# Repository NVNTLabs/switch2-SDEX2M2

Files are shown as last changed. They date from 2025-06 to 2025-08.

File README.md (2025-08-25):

# NVNT's SDEX2M2 (MicroSD Express to M.2) Adapter Project



SDEX2M2 (Micro**SD** **Ex**press to **M2**) is an adapter for the Nintendo Switch 2 which converts the MicroSD Express slot to a NVME M.2 (M-Key) slot. Think MicroSD Express cards are difficult to find or expensive? Looking to expand your storage for cheaper? Just use the NVME M.2 SSD that you have, and/or can easily find! The project is open source hardware under the GPLv3 License.

This project also encompasses the sister-project of "MicroSD Express to SD Express" adapter, which is a pin-to-pin conversion kit allowing full size SD Express cards to be used on the Nintendo Switch 2.

---

## 📚 Table of Contents
- **Introduction**
  - [Goals](#goals)
  - [Status](#status)
  - [Warnings](#warnings)
- **Assets & Hardware Info**
  - [Bill of Materials (BOM)](#bill-of-materials-bom)
  - [PINOUT & LEGEND](#pinout--legend)
    - [MicroSD Express to M.2 NVMe Mapping](#microsd-express-to-m2-nvme-mapping)
    - [M.2 NVMe Pinout](#m2-nvme-pinout)
    - [MicroSD Express Pinout](#microsd-express-pinout)
- **PCB's / Boards**
  - [Wiring Schematic](#wiring-schematic)
  - [MicroSD Express Dummy Card](#microsd-express-dummy-card)
  - [MicroSD Express to FPC Flex Cable Connector](#microsd-express-to-fpc-flex-cable-connector)
  - [MicroSD Express Breakout Board](#microsd-express-breakout-board)
  - [NVMe M.2 SSD Breakout Board](#nvme-m2-ssd-breakout-board)
  - [MicroSD Express to SD Express Prototype Adapter](#microsd-express-to-sd-express-prototype-adapter)
  - [SDEX2SDEX MicroSD Express to NVMe M.2 Prototype Pin-to-Pin Adapter WIP](#sdex2sdex-microsd-express-to-nvme-m2-prototype-pin-to-pin-adapter)
  - [MicroSD Express Sniffer for Switch 2 Handshake](#microsd-express-sniffer)
- [License](#license)

---

## How is this possible?

This is possible because the Nintendo Switch 2's MicroSD Express slot supports the SD Express 7.1 standard, which exposes a **true PCIe Gen3 x1 interface** and utilizes the **NVMe protocol** for communication.

This adapter simply maps PCIe x1 from the Switch 2’s MicroSD Express slot to a standard M.2 2230 NVMe SSD. After further research and review from users, an onboard mcu/fpga will be required for the handshake process with the Switch 2.

Currently, we've developed a sniffer board which will be used to facilitate this.

---

## Goals

- ✅ Create Pinout & Pin Definitions (UPDATED!)
- ✅ Create Footprints for MicroSD Express
- ✅ Create Schematic for PCB layout
- ✅ Create Dummy MicroSD Express Card V2
- ✅ Create M.2 Breakout for prototyping (Updated 2-layer PCB)
- ✅ Create MicroSD Express Breakout Board V0.1 (Updated 2-layer PCB)
- ✅ Create MicroSD Express to SD Express Adapter (Experimental, Updated 2-layer PCB)
- ✅ Create BOM for fabrication and sourcing (WIP)
- ✅ Create MicroSD Express to NVMe M.2 SSD Pin to Pin Adapter (Proof of concept)
- ✅ Create basic 3D printable enclosures/shells for the PCBs
- ✅ Create MicroSD Express Sniffer PCB for capturing Nintendo Switch 2 Handshake (for getting NVMe drives to be functional!)
- 🔲 Create MicroSD Express to NVMe M.2 SSD Adapter with FPGA/MCU Proto (for handshake with Nintendo Switch 2) **(in progress)**
- ✅ Create MicroSD Express to Flex Cable Adapter
- 🔲 Create Flex Cable to NVMe Adapter **(in progress)**
- 🔲 Create MicroSD Express to NVMe M.2 SSD Dock **(in progress)**

---

## Status

Work in progress. Currently, a prototype with handshake capability with the Switch 2 and also designs for the final product design are being worked on.

An early proof of concept prototype of the SDEX2M2 MicroSD Express to NVMe M.2 SSD Adapter has been made, but it does lack Switch 2 compatibility. 

**For prototyping, a new MicroSD Express sniffer has been uploaded which is used for capturing the signal/handshake that the Nintendo Switch 2 uses for communicating with the MicroSD Express card. With this, we are one step closer to our goal!**

Additionally, production-ready 2-layer PCBs for the MicroSD Express breakout board, NVMe breakout board, and the MicroSD Express to FPC Connector (which may be used in the final design) have been uploaded.

The MicroSD Express to SD Express adapter production ready prototype board has been uploaded as well, for users with full-size SD Express cards.

Basic 3D printable shells have been added too, for convenience.

---

## Warnings

- Use at your own risk. We are **not liable** for any damage to your drive, Switch 2, or other devices.
- Only use **low-voltage, low-power M.2 2230 NVMe drives**.
- **Do not use this in legacy MicroSD slots** (e.g., original Nintendo Switch).
  
---

## Bill of Materials (BOM)

| Reference | Quantity | Description | Part Number | Manufacturer |
|---|---|---|---|---|
| J2 | 1 | M.2 Socket (M-Key, 2230) | 114020 | Amphenol |
| FB1 | 1 | Ferrite Bead 220Ω@100MHz 0603 | BLM18PG221SN1D | Murata/OEM |
| PCB | 1 | 4-Layer PCB | N/A | Fabricated | * |
|* | 1 | 10kΩ – 100kΩ Pull Up Resistor (Optional) | N/A | * |

The optional resistor is for the PERST# lane, may help with state when idle. Not sure if needed until prototyping commences.

---

## PINOUT & LEGEND

### MicroSD Express to M.2 NVMe Mapping

| microSD Express Pin  | PCIe Function | M.2 M-Key Pin(s) | M.2 Function |
| --- | --- | --- | --- |
| 7 (Row 1) | REFCLK+ | B10 | REFCLK+ |
| 8 (Row 1) | REFCLK− | B11 | REFCLK− |
| 2 (Row 1) | PERST# | A11 | PERST# |
| 1 (Row 1) | CLKREQ# | B8 | CLKREQ# |
| 11 (Row 2) | TX+ | B23 | PCIe TX+ |
| 12 (Row 2) | TX− | B24 | PCIe TX− |
| 14 (Row 2) | RX- | A21 | PCIe RX+ |
| 15 (Row 2) | RX+ | A22 | PCIe RX− |
| 4 (Row 1) | 3.3V VDD | B2, B3, B4 | 3.3V Power |
| 6, 10, 13, 16 | GND | A1, A4, etc. | Ground |

---

### M.2 NVMe Pinout

| Pin | Name | Function |
|---|---|---|
| A11 | PERST# | PCIe Reset |
| A21 | RX+ | PCIe RX+ (to host) |
| A22 | RX− | PCIe RX− (to host) |
| B10 | REFCLK+  | PCIe Reference Clock + |
| B11 | REFCLK−  | PCIe Reference Clock − |
| B23 | TX+ | PCIe TX+ (from host) |
| B24 | TX− | PCIe TX− (from host) |
| B2–B4 | 3.3V | Power Supply |
| A1, A4  | GND | Ground Pins |

---

### MicroSD Express Pinout

In SD Mode &* PCIe Mode

| Pin | Row 1 Contact | SD Mode Function | PCIe Mode Function |
| --- | --- | --- | --- |
| 1 | DAT2 | Data Line 2 | CLKREQ# (Power / Signal Mgmt) |
| 2 | DAT3 / CD | Data Line 3 / CD | PERST# (Reset) |
| 3 | CMD | Command Line | CMD (unused in PCIe mode) |
| 4 | VDD | 3.3V Power | 3.3V Power |
| 5 | CLK | Clock Line | CLK (unused in PCIe mode) |
| 6 | VSS | Ground | Ground |
| 7 | DAT0 | Data Line 0 | REFCLK+ (PCIe Ref Clock) |
| 8 | DAT1 | Data Line 1 | REFCLK− (PCIe Ref Clock) |

| Pin | Row 2 Contact | PCIe Function |
| --- | --- | --- |
| 9 | 1V8 | 1.8 Volts |
| 10  | VSS2 | Ground for isolation |
| 11  | TX+ | PCIe TX+ (Transmit) |
| 12  | TX- | PCIe TX- (Transmit) |
| 13  | VSS3 | Ground for isolation |
| 14  | RX- | PCIe RX- (Receive) |
| 15  | RX+ | PCIe RX+ (Receive) |
| 16  | VSS4 | Ground for isolation |
| 17  | 1V2 | 1.2 Volts |

Please note: Row 2 is only operational in PCIe Mode. Row 2 is based on M1cha's (https://github.com/M1cha/sdexpress_pcbs) schematic.

---

### MicroSD Express Card to SD Express Slot Pinout

| **MicroSD Express Pin** | **Function (PCIe Mode)**  | **SD Express Slot Pin** | **Function in Slot** | 
| --- | --- | --- | --- |
| 1 DAT2 | CLKREQ# | 51 | CLKREQ# (Power / Signal Mgmt) | 
| 2 DAT3 / CD | PERST# | 52 | PERST# (Reset line)  |
| 3 CMD | CMD (unused) | — | CMD (unused in PCIe mode) | 
| 4 VDD | 3.3V VDD | 18, 48 | VDD |
| 5 CLK | CLK (unused) | — | — | 
| 6 VSS | GND (VSS1) | 17, 47, 49, 50 | GND |
| 7 DAT0 | REFCLK+ | 45 | REFCLK+ | 
| 8 DAT1 | REFCLK− | 46 | REFCLK− | 
| 9 1V8 | 1.8V VDD (VDD2) | 1, 2, 3 (often shared)  | VDD 1.8 Volts | 
| 10 VSS2 | GND (VSS2) | 17, 47, etc. | GND (GND Ground for isolation)| 
| 11 TX+ | TX+ | 39 | PCIe TX+ (Transmit)  |
| 12 TX- | TX− | 41 | PCIe TX- (Transmit)  |
| 13 VSS3 | GND  (VSS3) | 17, 47, etc. | GND (Ground for isolation)| 
| 14 RX- | RX− | 35 | PCIe RX- (Receive)|
| 15 RX+ | RX+ | 37 | PCIe RX+ (Receive)|
| 16 VSS4 | GND (VSS4) | 17, 47, etc. | GND (Ground for isolation)| 
| 17 1V2 | 1.2V VDD (VDD3, optional) | — | Not used (May be unused)|

Note: WIP

---

### Wiring Schematic



Still a WIP. Some discrepencies may exist.

---

### MicroSD Express Dummy Card

A dummy card has been created (thanks to M1cha's design examples!), for reference. Files have been attached.



---

### MicroSD Express to FPC Flex Cable Connector

A MicroSD Express to Flex Cable Connector (FPC) has been created for reference. Schematic, Geberer and PCB files have been attached.



---

### MicroSD Express Breakout Board

A production-ready 2-layer breakout board for MicroSD Express has been created (codenamed: "The Key"). Files have been attached in the repo. The purpose of this is for prototyping with a breadboard.



---

### NVMe M2 SSD Breakout Board

A breakout board for a NVMe M.2 SSD slot (M-key) has been created. Files have been attached in the repo. The purpose of this is for prototyping with a breadboard.



---

### MicroSD Express to SD Express Prototype Adapter

An extremely experimental production ready MicroSD Express to **Full Size** SD Express Slot adapter has been made. The purpose of this is to allow full size SD Express cards to be inserted into the Nintendo Switch 2.

Please be aware that it is untested as of the time of writing.



---

### SDEX2SDEX MicroSD Express to NVMe M.2 Prototype Pin-to-Pin Adapter

A production-ready (but experimental) 2-layer PCB for the SDEX2M2 MicroSD Express to NVMe M.2 adapter has been uploaded. 

Please note that this is a pin-to-pin adapter, and is not capable of completing the handshake with Nintendo Switch 2. It is for proof of concept, and is untested as of the time of writing.



---

### MicroSD Express Sniffer

A experimental PCB MicroSD Express sniffer has been uploaded. **This is used for capturing the handshake signal/commands from the Nintendo Switch 2**.

Please note: The MicroSD Express card slot on the PCB in the picture below is for placeholder only as it doesn't exactly match the dimensions of the one used in the actual PCB itself.



---

## License

NVNT SDEX2M2 License

This hardware design is licensed under the **CERN Open Hardware License Version 2 – Strongly Reciprocal (CERN-OHL-S v2)**.

The software/firmware design is licensed under the **GNU General Public License v3.0 (GPLv3)**

The documentation and readme is licensed under the **Creative Commons Attribution-ShareAlike 4.0 International (CC-BY-SA 4.0)**.

See [LICENSE](LICENSE.txt), [LICENSE-HARDWARE](LICENSE-HARDWARE.txt) and [LICENSE-DOCUMENTATION](LICENSE-DOCUMENTATION.txt) for more information.

---

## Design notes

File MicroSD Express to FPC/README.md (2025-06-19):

# microSD Express card to FPC

> [!WARNING]
> This is WIP and based on M1cha's perimeters.

JLCPCB order parameters:

- **Gerber file**: usdex_card-to-fpc_Y5
- **Build Time**: 5-6 days
- **Base Material**: FR-4
- **Layers**: 6
- **Dimension**: 11 mm* 18 mm
- **PCB Qty**: 5
- **Product Type**: Industrial/Consumer electronics
- **Different Design**: 1
- **Delivery Format**: Single PCB
- **PCB Thickness**: 0.8mm
- **Specify Stackup**: yes JLC06081H-2116
- **Impedance Control**: No requirement
- **PCB Color**: Green
- **Silkscreen**: White
- **Material Type**: FR-4 TG155
- **Via Covering**: Epoxy Filled & Capped
- **Surface Finish**: ENIG Gold Fingers: 2U"
- **Deburring/Edge rounding**: Yes
- **Outer Copper Weight**: 1 oz
- **Inner Copper Weight**: 0.5 oz
- **Gold Fingers**: Yes
- **Beveling**: No
- **Electrical Test**: Flying Probe Fully Test
- **Castellated Holes**: no
- **Press-Fit Hole**: No
- **Edge Plating**: No
- **Mark on PCB**: Remove Mark
- **Blind Slot**: No
- **Min via hole size/diameter**: 0.3mm/(0.4/0.45mm)
- **4-Wire Kelvin Test**: No
- **Paper between PCBs**: No
- **Appearance Quality**: IPC Class 2 Standard
- **Confirm Production file**: Yes
- **Silkscreen Technology**: Ink-jet/Screen Printing Silkscreen
- **Package Box**: With JLCPCB logo
- **Inspection Report**: No
- **Board Outline Tolerance**: ±0.2mm(Regular)

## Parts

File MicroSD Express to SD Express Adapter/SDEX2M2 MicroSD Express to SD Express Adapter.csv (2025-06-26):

Reference | Qty | Value | DNP | Exclude from BOM | Exclude from Board | Footprint | Datasheet
J1 | 1 | SDEX2M2 MicroSD Express to SD Express Adapter |  |  |  | m1cha:usdex-male-open_bottom
J2 | 1 | GSD2100407THR |  |  |  | GSD2100407THR:AMPHENOL_GSD2100407THR

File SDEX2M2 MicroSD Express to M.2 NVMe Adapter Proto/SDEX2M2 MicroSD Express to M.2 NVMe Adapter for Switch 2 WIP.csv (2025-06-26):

Reference | Qty | Value | DNP | Exclude from BOM | Exclude from Board | Footprint | Datasheet
J1 | 1 | SDEX2M2 MicroSD Express to SD Express Adapter |  |  |  | m1cha:usdex-male-open_bottom
J2 | 1 | Conn_01x02_Pin |  |  |  | Connector_PinHeader_2.00mm:PinHeader_1x02_P2.00mm_Vertical | ~
J4 | 1 | 10130616-067R2LF |  |  |  | 10130616-067R2LF:AMPHENOL_10130616-067R2LF
R1 | 1 | R_Small (Pull-Up) 33kΩ |  |  |  | Resistor_SMD:R_0603_1608Metric | ~

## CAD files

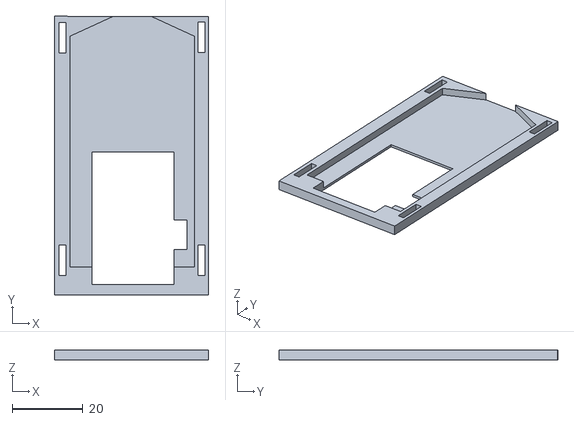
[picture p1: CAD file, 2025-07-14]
3D Printable Shells/SDEX2M2 Prototype Shell Top.stl
43.5 x 78.6 x 2.96

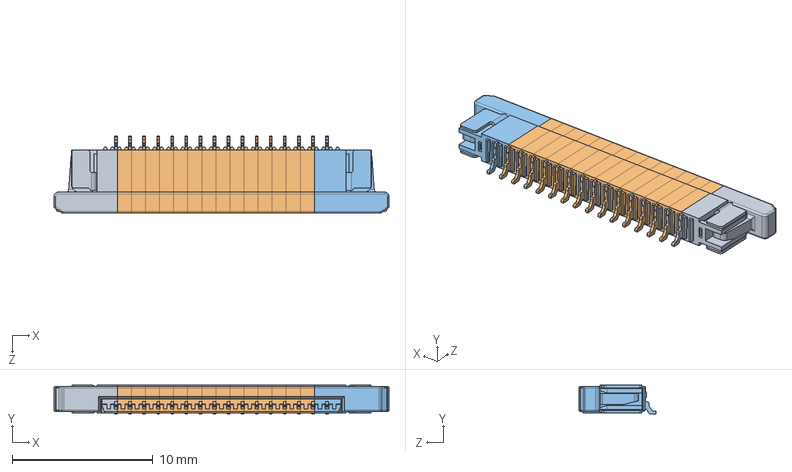
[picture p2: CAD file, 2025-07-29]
MicroSD Express to FPC/F52R-1A7H1-11016--3DModel-STEP-56544.STEP
23.8 x 2.05 x 5.50 mm
F52R_L.STEP
F52R_M.STEP x 14
F52R_R.STEP

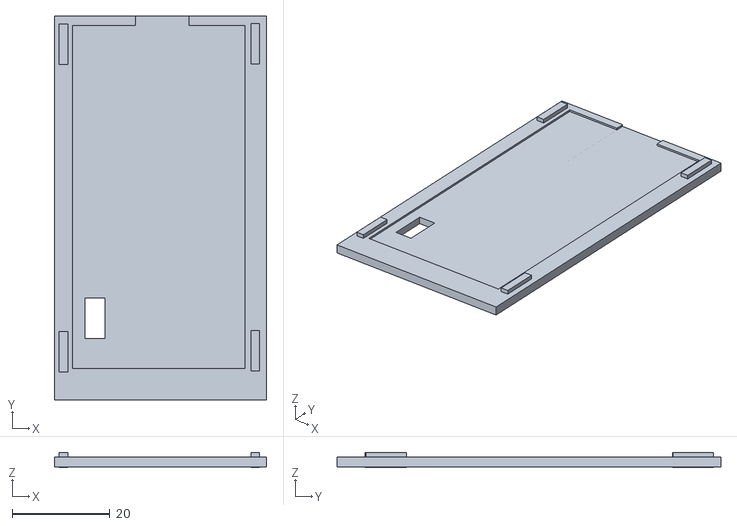
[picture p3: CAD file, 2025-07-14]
3D Printable Shells/SDEX2M2 Prototype Shell Bottom.stl
43.5 x 78.7 x 3.00

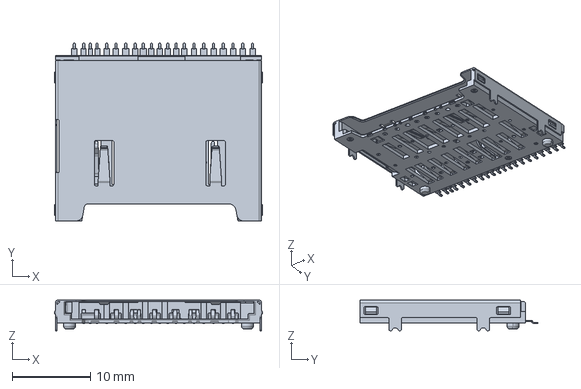
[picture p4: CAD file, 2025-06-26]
MicroSD Express to SD Express Adapter/GSD2100407THR--3DModel-STEP-418109.STEP
26.6 x 22.8 x 3.95 mm

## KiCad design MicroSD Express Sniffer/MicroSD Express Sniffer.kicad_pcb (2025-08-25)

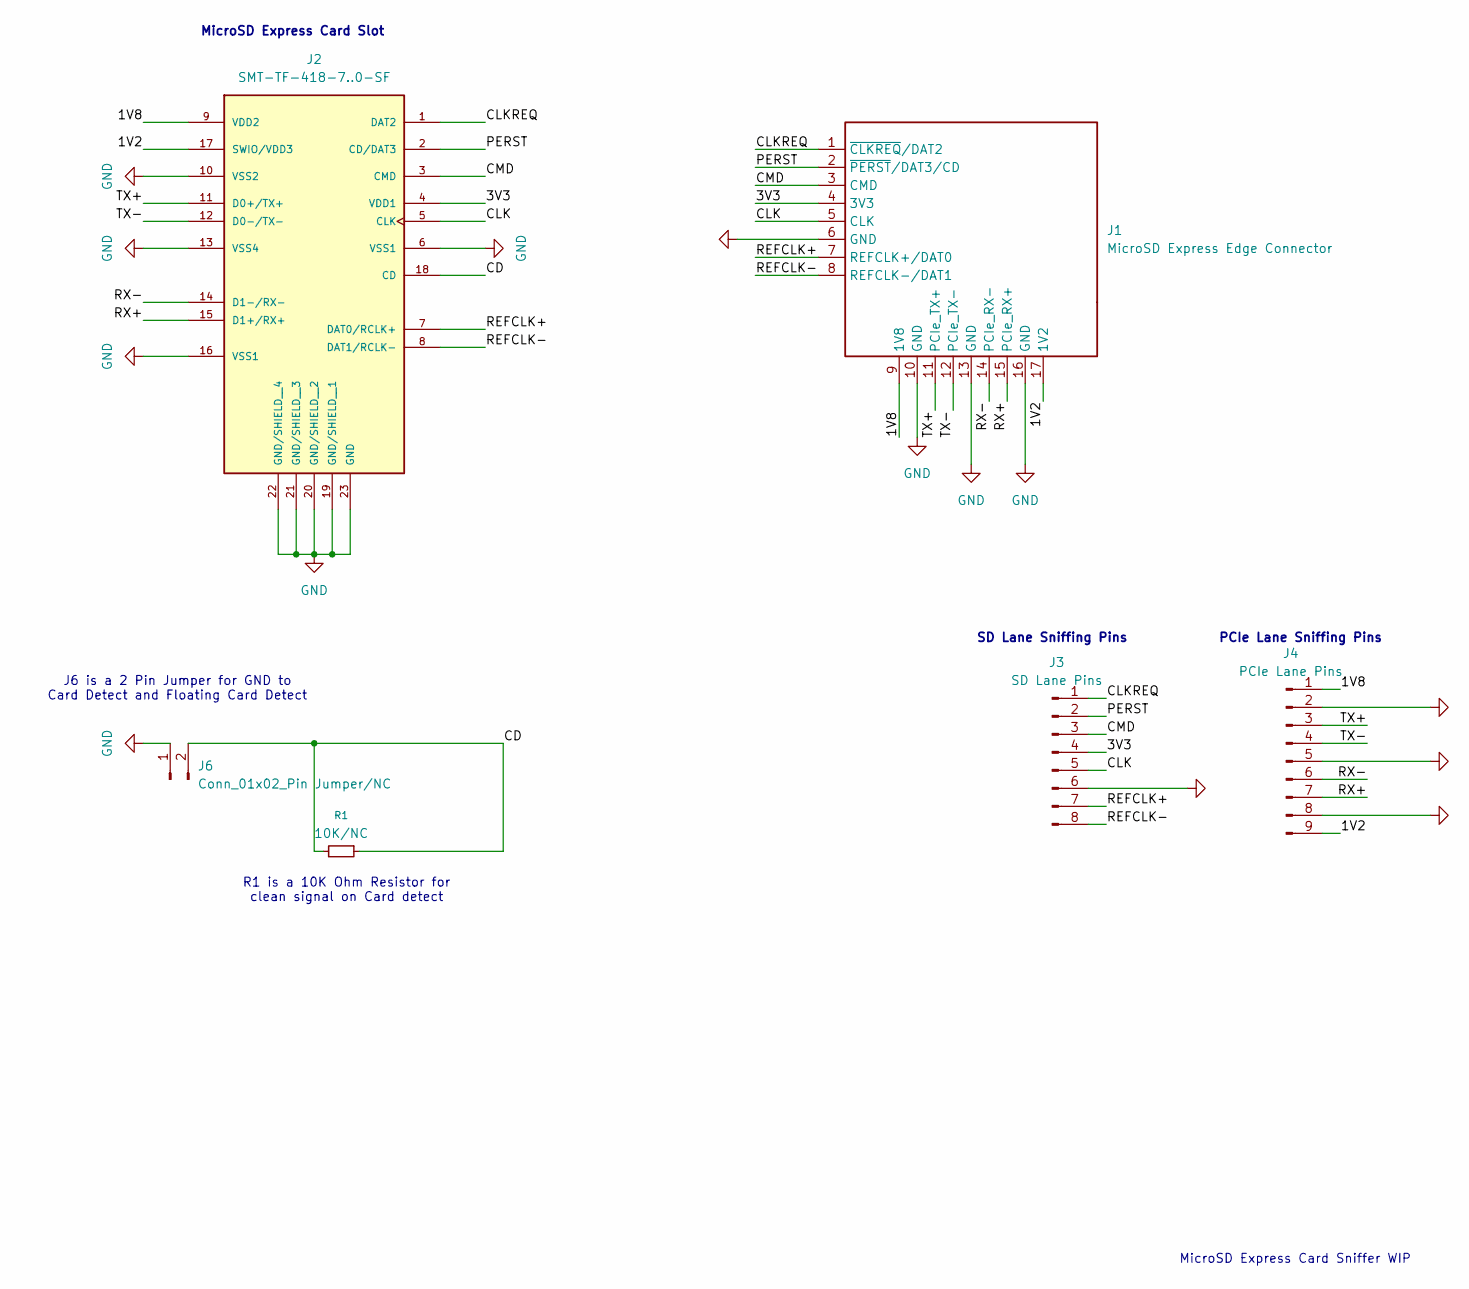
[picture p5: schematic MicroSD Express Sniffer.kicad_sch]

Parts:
J1: MicroSD Express Edge Connector; usdex-male-open_bottom
J2: SMT-TF-418-7..0-SF; SMT_TF_418__7.0_SF; PARTREV AX6
J3: SD Lane Pins; PinHeader_1x08_P2.54mm_Vertical
J4: PCIe Lane Pins; PinHeader_1x09_P2.54mm_Vertical
J6: Conn_01x02_Pin Jumper/NC; PinHeader_1x02_P2.54mm_Vertical
R1: 10K/NC; R_0603_1608Metric

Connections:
/1V2: J1.17 (1V2), J2.17 (SWIO/VDD3), J4.9
/1V8: J1.9 (1V8), J2.9 (VDD2), J4.1
/3V3: J1.4 (3V3), J2.4 (VDD1), J3.4
/CD: J2.18 (CD), J6.2, R1.1, R1.2
/CLK: J1.5 (CLK), J2.5 (CLK), J3.5
/CLKREQ: J1.1 (~CLKREQ/DAT2), J2.1 (DAT2), J3.1
/CMD: J1.3 (CMD), J2.3 (CMD), J3.3
/PERST: J1.2 (~PERST/DAT3/CD), J2.2 (CD/DAT3), J3.2
/REFCLK+: J1.7 (REFCLK+/DAT0), J2.7 (DAT0/RCLK+), J3.7
/REFCLK-: J1.8 (REFCLK-/DAT1), J2.8 (DAT1/RCLK-), J3.8
/RX+: J1.15 (PCIe_RX+), J2.15 (D1+/RX+), J4.7
/RX-: J1.14 (PCIe_RX-), J2.14 (D1-/RX-), J4.6
/TX+: J1.11 (PCIe_TX+), J2.11 (D0+/TX+), J4.3
/TX-: J1.12 (PCIe_TX-), J2.12 (D0-/TX-), J4.4
GND: J1.6 (GND), J1.10 (GND), J1.13 (GND), J1.16 (GND), J2.6 (VSS1), J2.10 (VSS2), J2.13 (VSS4), J2.16 (VSS1), J2.19 (GND/SHIELD__1), J2.20 (GND/SHIELD__2), J2.21 (GND/SHIELD__3), J2.22 (GND/SHIELD__4), J2.23 (GND), J3.6, J4.2, J4.5, J4.8, J6.1

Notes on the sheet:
SD Lane Sniffing Pins
R1 is a 10K Ohm Resistor for clean signal on Card detect
J6 is a 2 Pin Jumper for GND to Card Detect and Floating Card Detect
MicroSD Express Card Slot
PCIe Lane Sniffing Pins
MicroSD Express Card Sniffer WIP

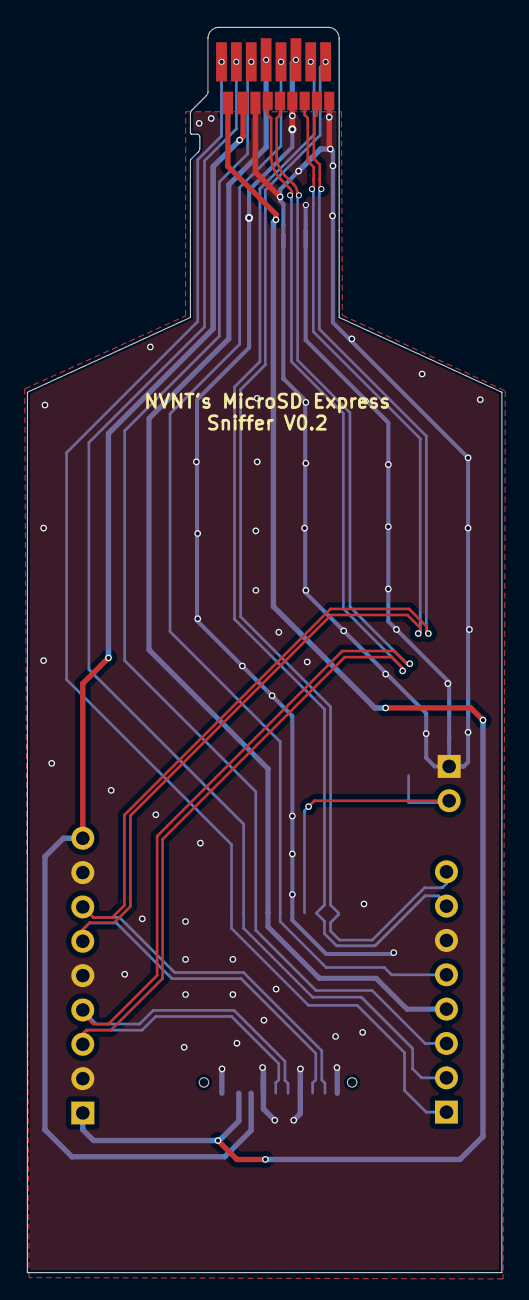
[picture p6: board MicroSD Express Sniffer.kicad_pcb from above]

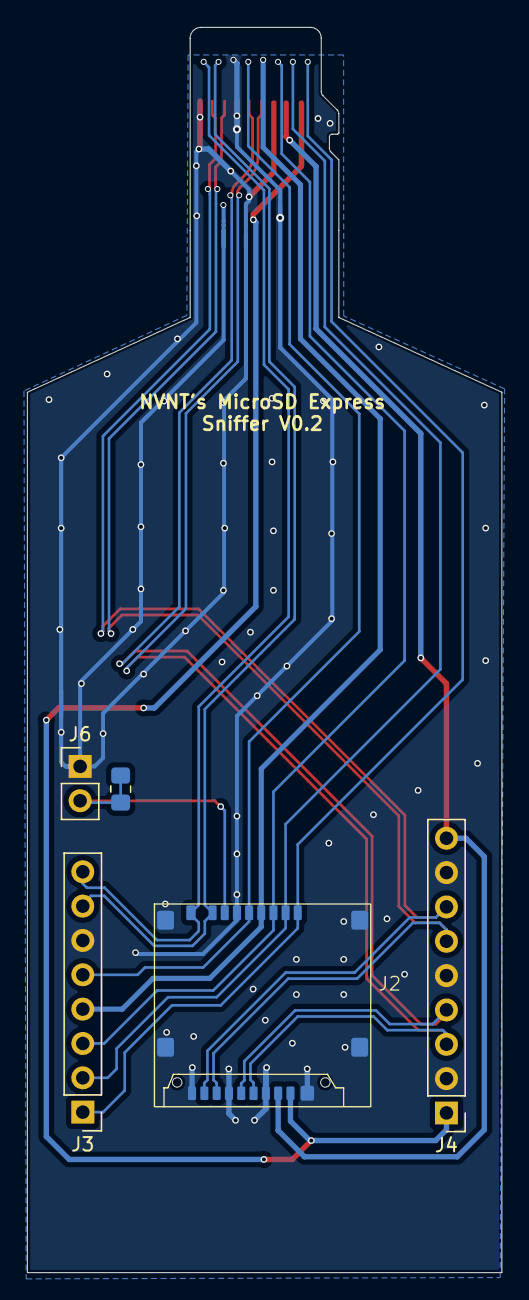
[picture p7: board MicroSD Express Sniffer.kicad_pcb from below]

Board: 2 copper layers, 35.1 x 92.1 mm, 6 parts (5 on the bottom side), 15 nets.

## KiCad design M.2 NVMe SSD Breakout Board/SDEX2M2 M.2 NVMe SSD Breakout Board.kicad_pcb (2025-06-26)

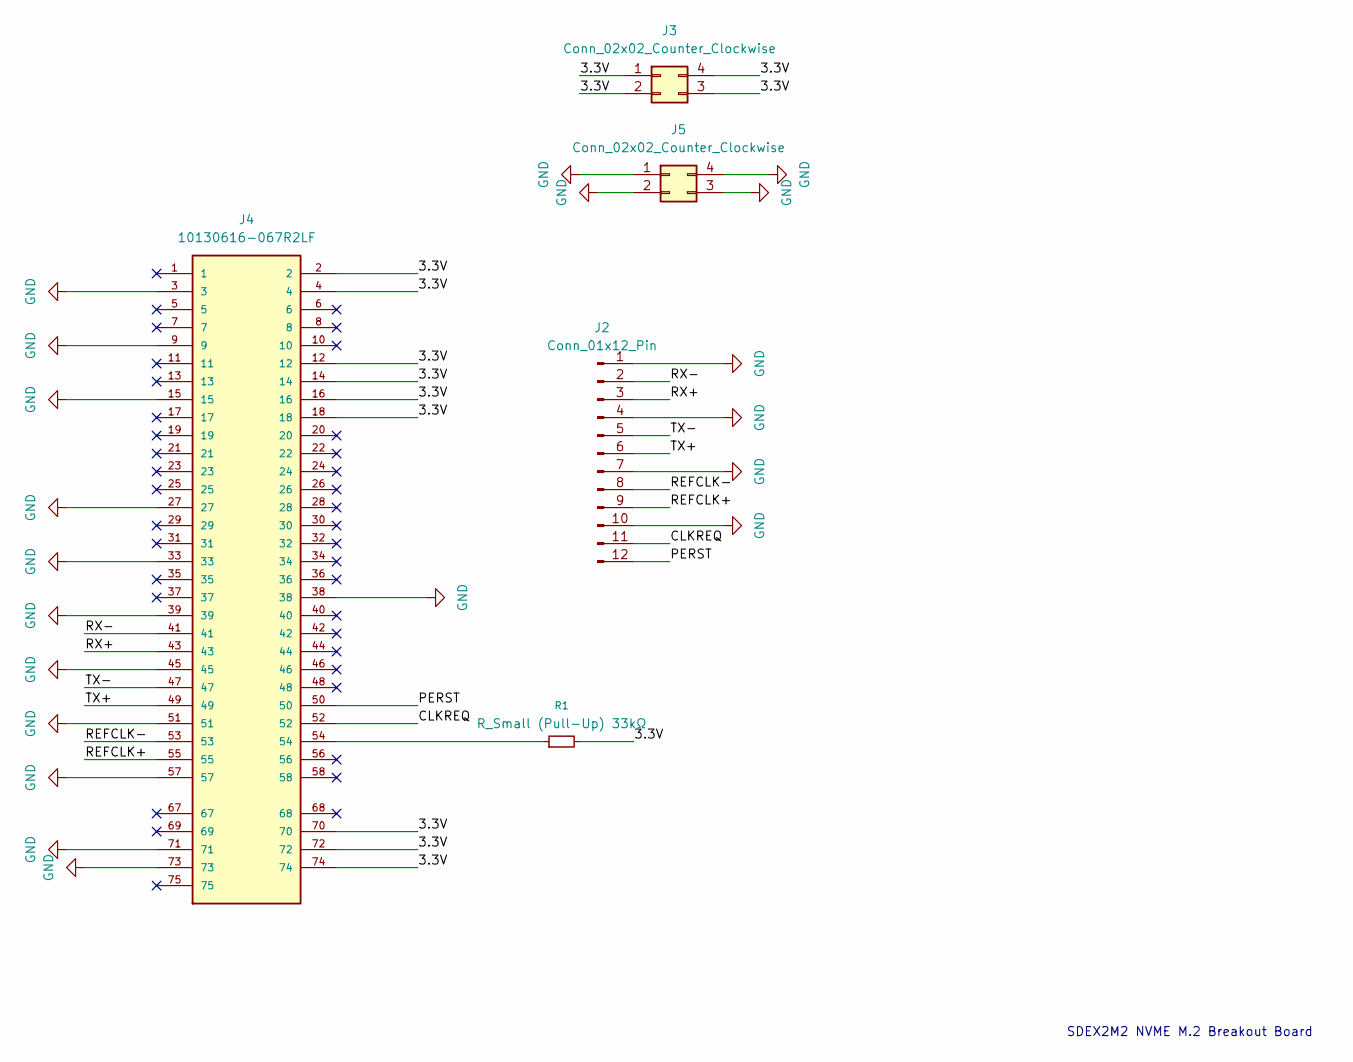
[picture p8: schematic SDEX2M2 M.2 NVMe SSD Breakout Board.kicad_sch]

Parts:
J2: Conn_01x12_Pin; PinHeader_1x12_P2.00mm_Vertical
J3, J5: Conn_02x02_Counter_Clockwise; PinHeader_2x02_P2.00mm_Vertical
J4: 10130616-067R2LF; AMPHENOL_10130616-067R2LF; PARTREV C
R1: R_Small (Pull-Up) 33kΩ; R_0603_1608Metric

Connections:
/3.3V: J3.1, J3.2, J3.3, J3.4, J4.2, J4.4, J4.12, J4.14, J4.16, J4.18, J4.70, J4.72, J4.74, R1.2
/CLKREQ: J2.11, J4.52
/PERST: J2.12, J4.50
/REFCLK+: J2.9, J4.55
/REFCLK-: J2.8, J4.53
/RX+: J2.3, J4.43
/RX-: J2.2, J4.41
/TX+: J2.6, J4.49
/TX-: J2.5, J4.47
GND: J2.1, J2.4, J2.7, J2.10, J4.3, J4.9, J4.15, J4.27, J4.33, J4.38, J4.39, J4.45, J4.51, J4.57, J4.71, J4.73, J5.1, J5.2, J5.3, J5.4
unnamed: J4.54, R1.1

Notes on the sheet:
SDEX2M2 NVME M.2 Breakout Board

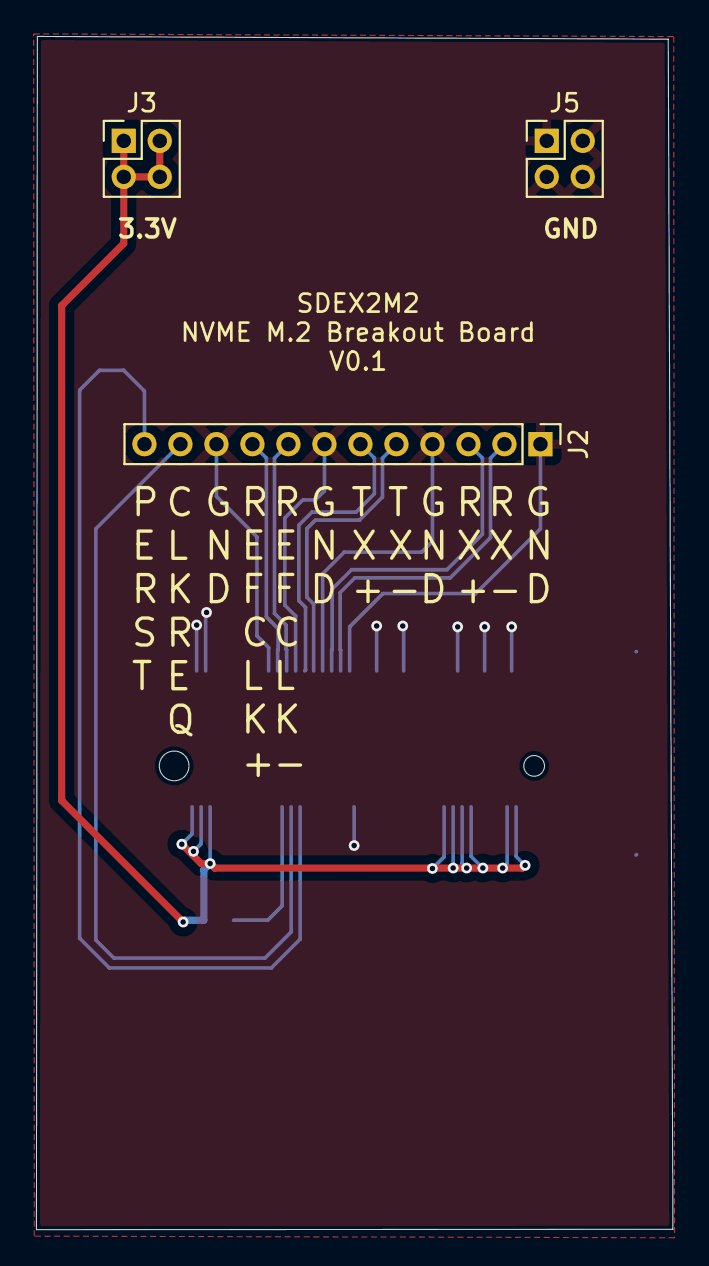
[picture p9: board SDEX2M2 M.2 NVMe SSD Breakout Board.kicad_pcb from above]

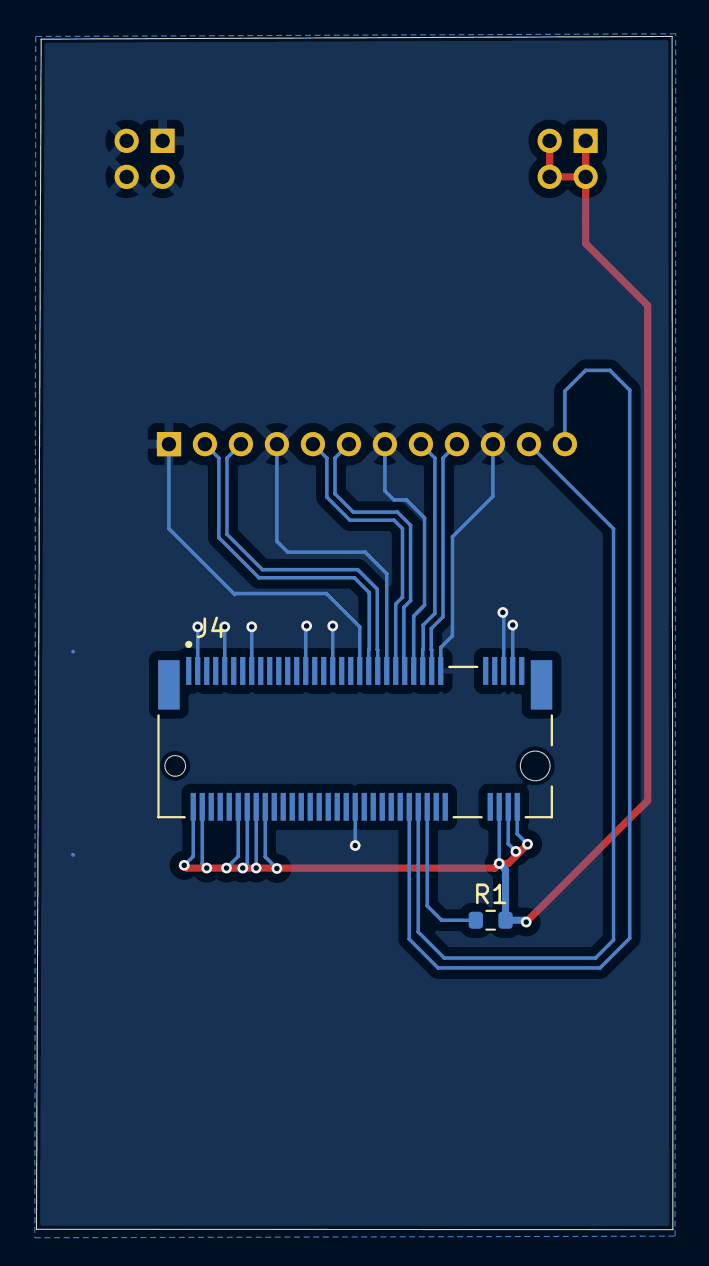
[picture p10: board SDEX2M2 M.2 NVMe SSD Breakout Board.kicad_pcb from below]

Board: 2 copper layers, 35.4 x 66.3 mm, 5 parts (2 on the bottom side), 11 nets.

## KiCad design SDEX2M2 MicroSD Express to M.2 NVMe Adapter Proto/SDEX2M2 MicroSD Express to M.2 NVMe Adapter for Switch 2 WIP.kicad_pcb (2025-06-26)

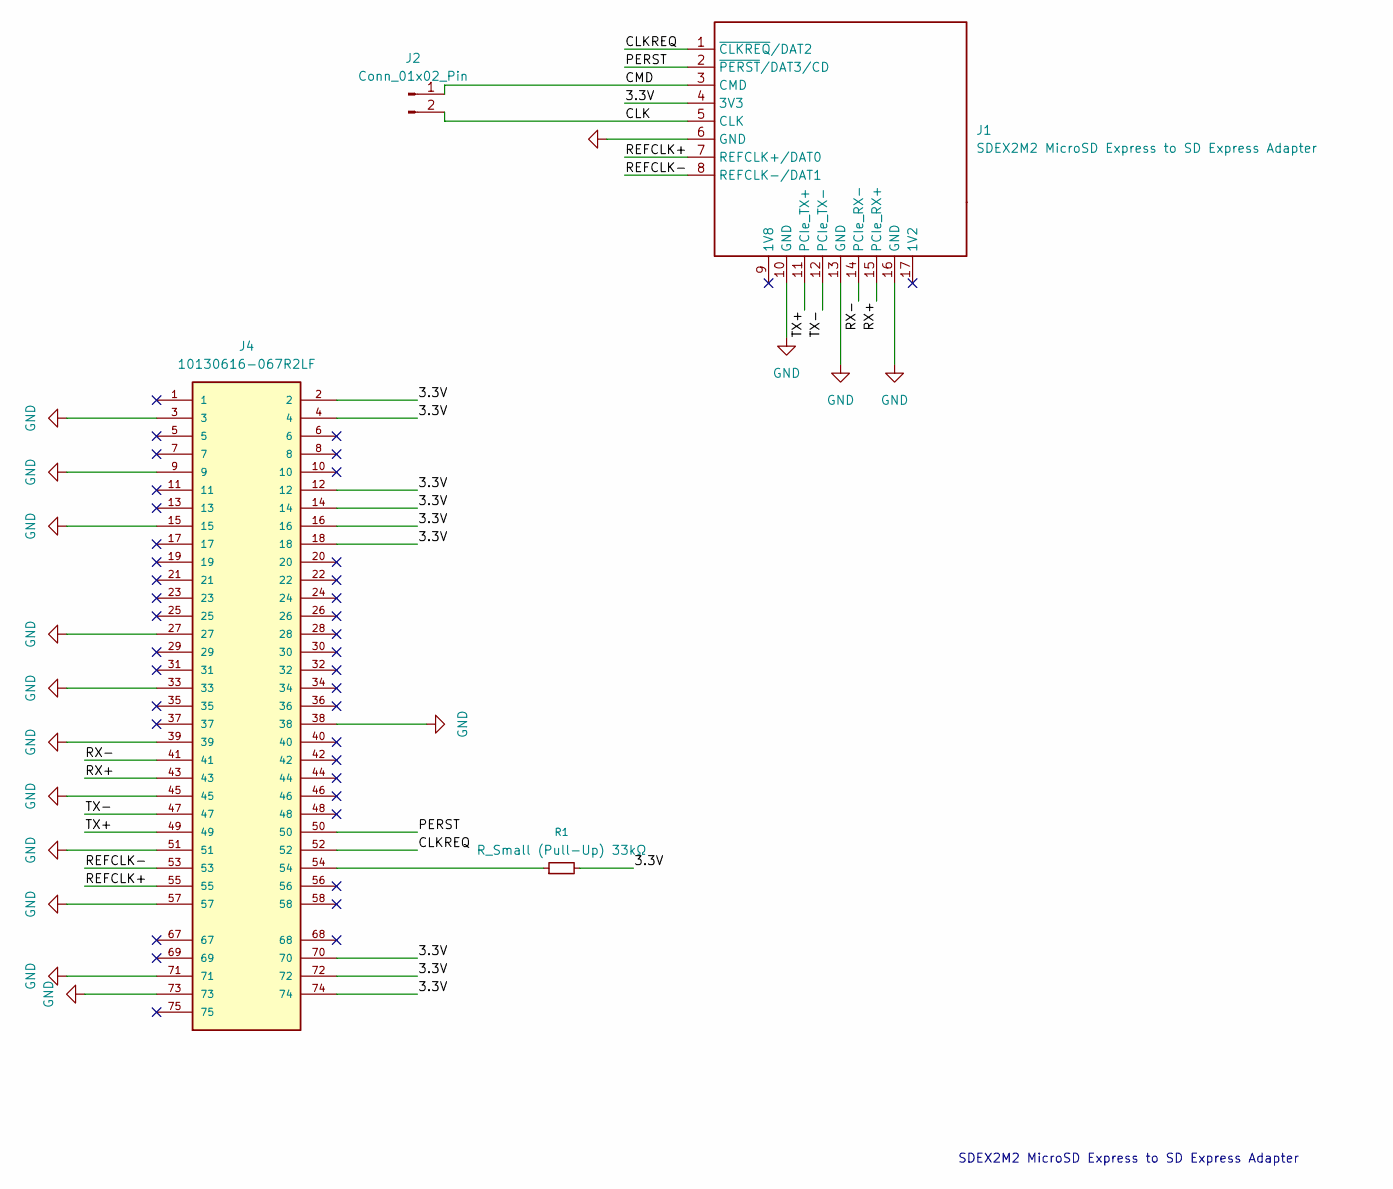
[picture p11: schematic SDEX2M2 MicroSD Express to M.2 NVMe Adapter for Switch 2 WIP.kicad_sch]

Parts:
J1: SDEX2M2 MicroSD Express to SD Express Adapter; usdex-male-open_bottom
J2: Conn_01x02_Pin; PinHeader_1x02_P2.00mm_Vertical
J4: 10130616-067R2LF; AMPHENOL_10130616-067R2LF; PARTREV C
R1: R_Small (Pull-Up) 33kΩ; R_0603_1608Metric

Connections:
/3.3V: J1.4 (3V3), J4.2, J4.4, J4.12, J4.14, J4.16, J4.18, J4.70, J4.72, J4.74, R1.2
/CLK: J1.5 (CLK), J2.2
/CLKREQ: J1.1 (~CLKREQ/DAT2), J4.52
/CMD: J1.3 (CMD), J2.1
/PERST: J1.2 (~PERST/DAT3/CD), J4.50
/REFCLK+: J1.7 (REFCLK+/DAT0), J4.55
/REFCLK-: J1.8 (REFCLK-/DAT1), J4.53
/RX+: J1.15 (PCIe_RX+), J4.43
/RX-: J1.14 (PCIe_RX-), J4.41
/TX+: J1.11 (PCIe_TX+), J4.49
/TX-: J1.12 (PCIe_TX-), J4.47
GND: J1.6 (GND), J1.10 (GND), J1.13 (GND), J1.16 (GND), J4.3, J4.9, J4.15, J4.27, J4.33, J4.38, J4.39, J4.45, J4.51, J4.57, J4.71, J4.73
unnamed: J4.54, R1.1

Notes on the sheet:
SDEX2M2 MicroSD Express to SD Express Adapter

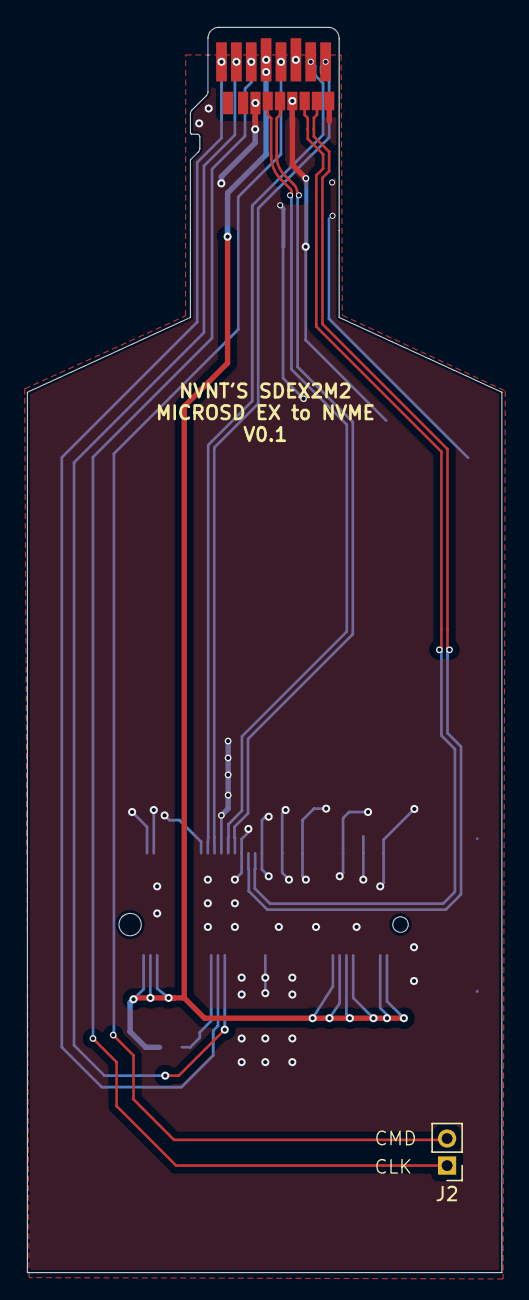
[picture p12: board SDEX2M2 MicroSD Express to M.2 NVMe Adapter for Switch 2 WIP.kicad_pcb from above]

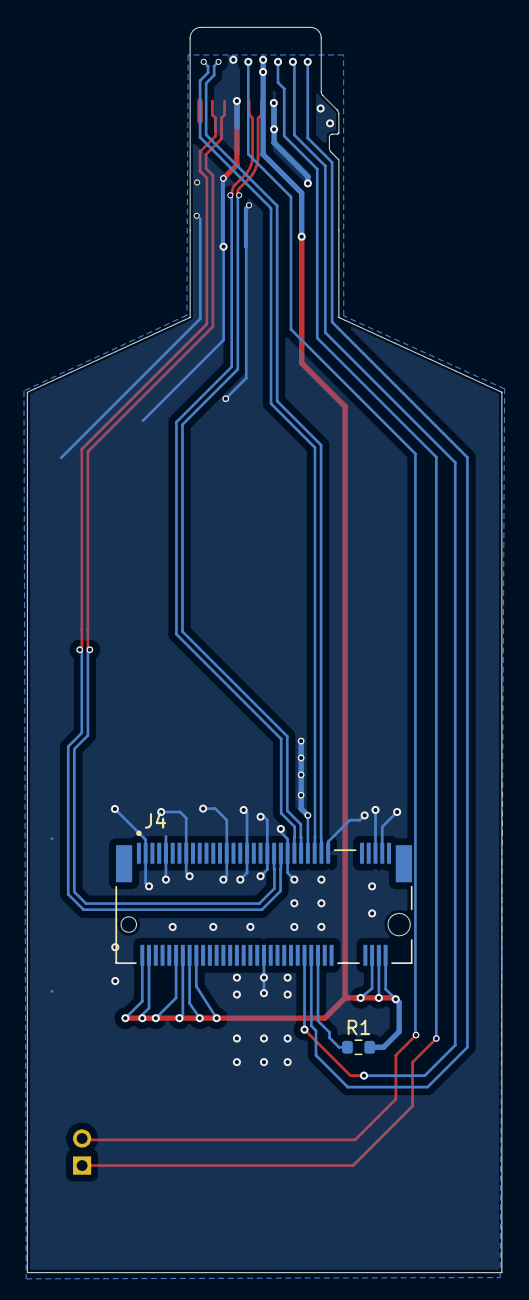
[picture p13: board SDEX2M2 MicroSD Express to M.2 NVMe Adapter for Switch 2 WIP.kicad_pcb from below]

Board: 2 copper layers, 35.1 x 92.1 mm, 4 parts (2 on the bottom side), 13 nets.

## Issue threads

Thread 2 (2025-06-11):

Flex PCB Adapter(?)

MasonT8198, 2025-06-11:
The stick-like design in its current form is easily prone to breaking and/or being knocked loose.

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

Perhaps a flex pcb design like common SD card extenders would be a better implementation for the projects final form?

Unsure how short the length could be due to pcie signaling etc but I imagine it's possible to have it at least long enough to be stuck to the back of the switch... possibly thin enough to be slid under the casing into the console (X Doubt on this one... but would be nice)

Closed 2025-06-11.

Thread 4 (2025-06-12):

一个未经验证的项目,希望可以提供参考

adsl95, 2025-06-12:
https://oshwhub.com/goldennebula/sd-express#5
只可惜他的设计是需要一个物理sdex卡做协议引导.
但反过来想,up的虚拟sdex卡也是独立的,硬件方面多少还是可以参考的吧.
尤其他这个设计就是使用的外部供电,是up主想实现的目标之一.
我不会英语就直接写中文了,希望这个对你的项目能有参考价值.

NVNTLabs, 2025-06-13:
Hi! Thank you for sharing this! 感谢您与我们分享这些信息。我会查看 ^_^

Garfius, 2025-07-10:
did it work on Switch 2? 有用吗？

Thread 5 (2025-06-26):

Question: Will the Nintendo handshake prevent this board from working for other applications?

j0o5t, 2025-06-26:
Would like to use this board to extend the memory of the Ubiquiti UDW, this comes with only a Micros SD slot, limiting storage options a lot. This great solution would make a lot of people happy i think!

NaruZosa, 2025-06-27:
MicroSD Express and MicroSD use different protocols, so the adapter won't work for the UDW which has a standard microSD slot.

The UDW has a built in SSD though, which might be upgradeable.

Happy for someone to correct me if I'm wrong.

NVNTLabs, 2025-06-29:
MicroSD and MicroSD Express are different. Regular MicroSD cards lack the pins that are essentially NVMe.  Unfortunately, my project wouldn’t work for your use case (as it does state to not use it in regular MicroSD slots). However. There may be other forms of storage that may be applicable to your use case, yet MicroSD would be the best bet there due to its compact size and cheap price.

NVNTLabs, 2025-07-01:
No problem!

Closed 2025-07-01.

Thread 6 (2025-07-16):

Will NVMEs provide better performance than SD Express or is the memory controller the limiting factor?

Merthan, 2025-07-16:
Sorry to create an issue for this, but am always wondering if this project can actually lead to better performance than SD Express as Games already take a performance hit when not on internal storage.

NVMEs are currently 14* faster than SD Express after all.
**I just wonder where the memory controller of the Switch 2 reaches it's maximum.**

Would be a great plus for this project if performance would actually be better than SD Express.

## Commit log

2025-06-18 Added MicroSD Express Breakout Board info
2025-06-18 Upload MicroSD Express breakout board
    [SDEX2M2 Breakout Board.kicad_pcb, SDEX2M2 Breakout Board.kicad_sch]
2025-06-18 Updated schematic and breakout board
    [SDEX2M2 Breakout Board.kicad_pcb, SDEX2M2 Breakout Board.kicad_sch]
2025-06-19 Added MicroSD Express to SD Express Adapter PCB
    [SDEX2M2 Breakout Board.kicad_pcb, SDEX2M2 MicroSD Express to SD Express Adapter.kicad_pcb, SDEX2M2 MicroSD Express to SD Express Adapter.kicad_sch]
2025-06-20 Uploaded M.2 NVMe Breakout Board
    [SDEX2M2 M.2 NVMe SSD Breakout Board.kicad_pcb, SDEX2M2 M.2 NVMe SSD Breakout Board.kicad_sch]
2025-06-20 Update README.md
    Updated with NVMe Breakout Board
2025-06-26 Update README.md
    Updated with 2-layer production ready board info & prototype SDEX2M2 adapter info.
2025-06-26 Uploaded 2-layer PCBs + SDEX2M2 Prototype
    Uploaded 2-layer production ready PCBs for each, and uploaded rough SDEX2M2 MicroSD Express to M.2 NVMe prototype.
    [GSD2100407THR--3DModel-STEP-418109.STEP, SDEX2M2 Breakout Board.kicad_pcb, SDEX2M2 Breakout Board.kicad_sch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]
2025-07-14 Added basic 3D printable shells
    [SDEX2M2 Prototype Shell Bottom.stl, SDEX2M2 Prototype Shell Top.stl]
2025-07-29 Added MicroSD Express to FPC Connector PCB
    [F52R-1A7H1-11016--3DModel-STEP-56544.STEP, F52R-1A7H1-11016.step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]
2025-08-25 Added MicroSD Express sniffer info
    Added info for MicroSD Express Sniffer PCB, required for capturing Switch 2 handshake. One step closer to NVMe!
2025-08-25 Added MicroSD Express Sniffer PCB
    A experimental PCB MicroSD Express sniffer has been uploaded. This is used for capturing the handshake signal/commands from the Nintendo Switch 2.
    [MicroSD Express Sniffer.kicad_pcb, MicroSD Express Sniffer.kicad_sch]
2025-10-09 Update README.md
    Updated with V0.3 of Switch 2 MicroSD Express Slot Sniffer. Used for capturing the handshake signal which will be used in the final adapter.
2025-10-09 Uploaded Switch 2 MicroSD Express Sniffer V0.3
    Updated the PCB design of the MicroSD Express sniffer to have better grounding and to use name-brand Amphenol MicroSD Express Slot. This is used for capturing the handshake which the final Switch 2 M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
2025-10-20 Update README.md
    Added more info for clarity of Pin-to-pin adapter
